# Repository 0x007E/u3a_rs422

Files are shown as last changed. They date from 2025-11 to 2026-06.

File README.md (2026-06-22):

  

# `U3A_rs422` - RS422 - Adapter for U3A



The `U3A_rs422` project is based on a ([THVD1452](#additional-information)) that ist used to change the RX/TX signals to the required differential signal level of TIA/TIA-485-A standard. It can simply be adapted to the [U3A-Module](https://github.com/0x007e/u3a).

> To use it with a [DSUB](https://www.reichelt.de/de/de/shop/produkt/d-sub-stecker_9-pol_flachbandkabel_ohne_isolator-6987) connector it is necessary to create a connector cable that can be plugged into the IDC connector.

| Experience | Level |
|:---|:-----:|
| Soldering | ?% |
| Mechanical  | ?% |

# Downloads

| Type | File | Description |
|:---:|:---:|:---|
| Schematic  | [pdf](https://github.com/0x007E/u3a_rs422/releases/latest/download/schematic.pdf) / [cadlab](https://cadlab.io/project/29767/main/files) | Schematic files |
| Board | [pdf](https://github.com/0x007E/u3a_rs422/releases/latest/download/pcb.pdf) / [cadlab](https://cadlab.io/project/29767/main/files) | Board file |
| Drill | [pdf](https://github.com/0x007E/u3a_rs422/releases/latest/download/drill.pdf) | Drill file |
| BoM | [xlsx](https://github.com/0x007E/u3a_rs422/releases/latest/download/bom.xlsx) / [html](https://github.com/0x007E/u3a_rs422/releases/latest/download/ibom.html) | Bill of Material as Excel/interactive HTML |
| PCB | [zip](https://github.com/0x007E/u3a_rs422/releases/latest/download/kicad.zip) / [tar](https://github.com/0x007E/u3a_rs422/releases/latest/download/kicad.tar.gz) | KiCAD/Gerber/BoM/Drill files |
| Mechanical | [zip](https://github.com/0x007E/u3a_rs422/releases/latest/download/freecad.zip) / [tar](https://github.com/0x007E/u3a_rs422/releases/latest/download/freecad.tar.gz) | FreeCAD/Housing and PCB (STEP/STL) files |

# Hardware

There are two parts of the hardware. The pcb and the housing of the `U3A_rs422`. The pcb is created with [KiCAD](#additional-information) and the housing with [FreeCAD](#additional-information). All files are built with `github actions` so that they are ready for a production environment. The housing is printed with a 3D-printer (`Dremel 3D40`).

## PCB

The circuit board is populated on both sides (Top, Bottom). The best way for soldering the `SMD` components is within a vapor phase soldering system and for the `THT` components with a standard soldering system.

### Top Layer

Top Layer

### Bottom Layer

Bottom Layer

## Mechanical

The housing has a tolerance of `0.2mm` on each side of the case. So the pcb should fit perfectly in the housing. The tolerance can be modified with `FreeCAD` in the `Parameter` Spreadsheet.

### Assembled

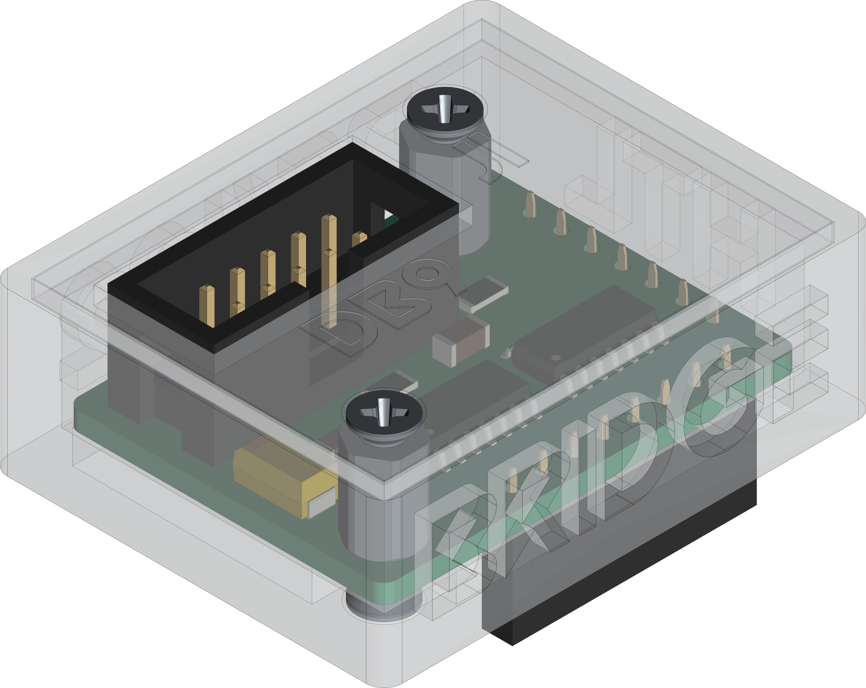
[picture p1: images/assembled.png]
Assembled


### Exploded

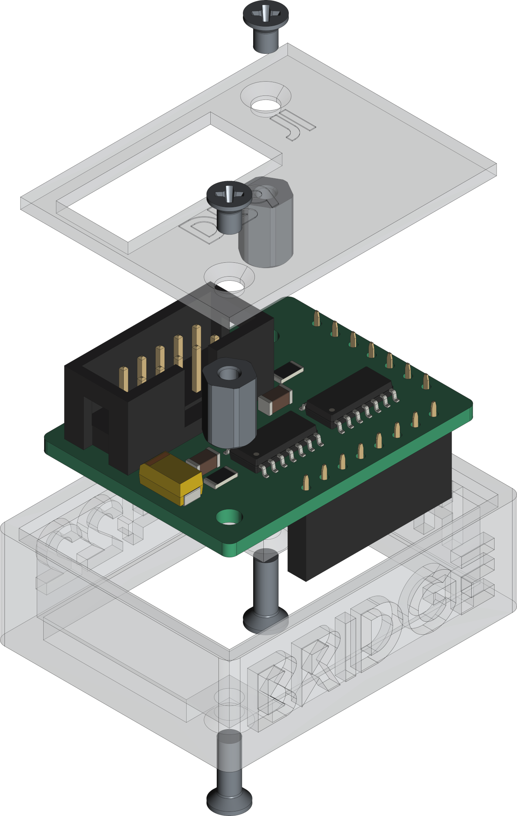
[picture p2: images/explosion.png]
Exploded


# Connection/Setup

The `U3A_rs422` is powerd over the `U3A` board with `5V`. The voltage of the pins are driven by a `THVD1452` for data transmission that meets the TIA/TIA-485-A standard.

## Simple loopback setup for testing purpose

``` bash
#
#            +------------------------------------+           +-----------------------------------+      +---------------------+
#            |J1                      T         J2|           |J2     U                       +---+---+  |                     |
#         +--+--+        U3A_rs422    E        +--+--+     +--+--+    S                U      |  USB  |--+ +-----------------+ |
#     +---+ RTS-| (1) D               R        | VCC +-----+ VCC |    B      UPDI      3      +---+---+  | | TeraTerm        | |
#   L | +-+ RTS+| (2) B               M        | GND +-----+ GND |    /    +---+---+   A          |      | | ~~~~~~~~        | |
#   O +-|-+ CTS-| (3) 9               I        |  X  +-----| PDI |    U    |   |   |              |      | | ~~~~~           | |
#   O   +-+ CTS+| (4)                 N        | CTS +-----+ CTS |    A    |   |   |              |      | | ~~~~~~~~~~~~    | |
#   P     + GND | (5)                 A        | RTS +-----+ RTS |    R    | X | X |              |      | |                 | |
#   B   +-+ RXD+| (6) ~               T        | TXD +-----+ TXD |    T    +---+---+     +-+      |      | +-----------------+ |
#   A +-|-+ RXD-| (7) P   T           I        | RXD +-----+ RXD |    /                 / /       |      |                     |
#   C | +-+ TXD+| (8) W   X           O        +--+--+     +--+--+    U               +-+-+-+-+-+-+      | Computer            |
#   K +---+ TXD-| (9) R   D           N           |           |       P               | 5V  | 3V3 |      |                     |
#         +--+--+     E   E           -> 120Ω     |           |       D               +-----+-----+      +---------------------+
#            |        N   N                       |           |       I         J4                |
#            |  +---+---+---+---+---+---+---+---+ |           | +---+---+---+---+---+---+---+---+ |
#            |  | V | C | C | D | D | D | R | G | |           | | V | C | C | D | D | D | R | G | |
#            +--+ C | B | B | C | T | C | I | N +-+           +-+ C | B | B | C | T | C | I | N +-+
#               | C | 3 | 2 | D | R | R |   | D |               | C | 3 | 2 | D | R | R |   | D |
#               +---+-+-+-+-+---+---+---+---+---+               +---+-+-+-+-+---+---+---+---+---+
#                     |   |                                           |   |
#                     |   +-------------------------------------------|---+
#                     +-----------------------------------------------+
```

# Additional Information

| Type | Link | Description |
|:---:|:---:|:---|
| THVD1452 | [pdf](https://www.ti.com/lit/ds/symlink/thvd1452.pdf) | UART / RS422 level converter |
| KiCAD | [web](https://www.kicad.org/) | KiCAD project page |
| FreeCAD | [web](https://www.freecad.org/) | FreeCAD project page |

---

R. GAECHTER

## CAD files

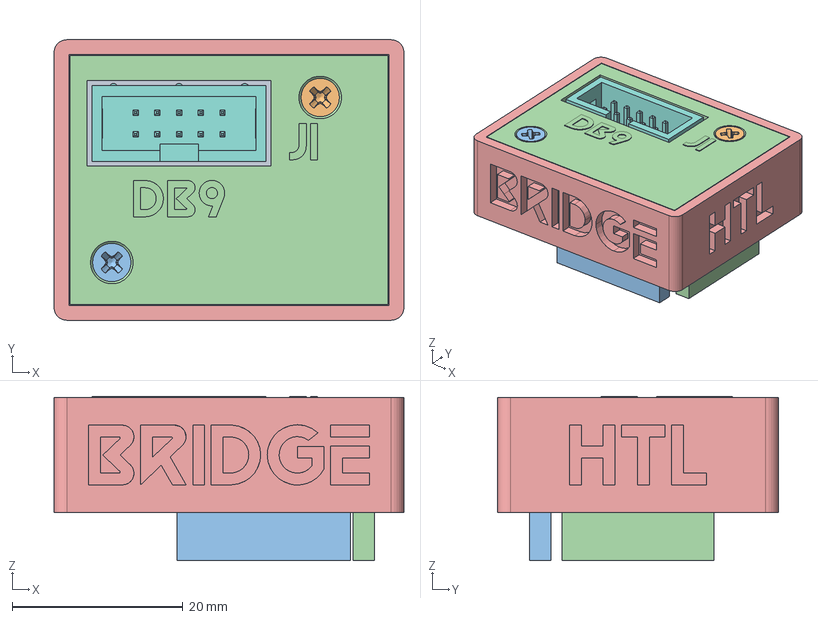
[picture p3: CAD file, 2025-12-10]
mechanical/housing.FCStd
40.9 x 32.8 x 19.2 mm
Pcb_c977
R3_R_1206_3216Metric_602aa173faeb
C3_C_1206_3216Metric_e174f7cd519c
R1_R_1206_3216Metric_1cd0ed1b88fb
C2_C_1206_3216Metric_51f7ab8182d4
U2_SOIC-14_3.9x8.7mm_P1.27mm_957f0b327e66
C1_CP_EIA_6032_28_Kemet_C_aa69b462bfbf
J1_IDC_Header_2x05_P254mm_Vertical_b8abcef818d7
U3_SOIC-14_3.9x8.7mm_P1.27mm_d777186c7664
R2_R_1206_3216Metric_6938828b103d
J4_PinSocket_1x08_P2.54mm_Vertical_36e3868fe61d
J2_PinSocket_1x07_P2.54mm_Vertical_e5fd038025c4
Case
M2.5x7.5x5-Spacer
M2.5x7.5x5-Spacer001
M2.5x8-Screw
M2.5x8-Screw001
M2.5x4-Screw
M2.5x4-Screw001
Acrylglass

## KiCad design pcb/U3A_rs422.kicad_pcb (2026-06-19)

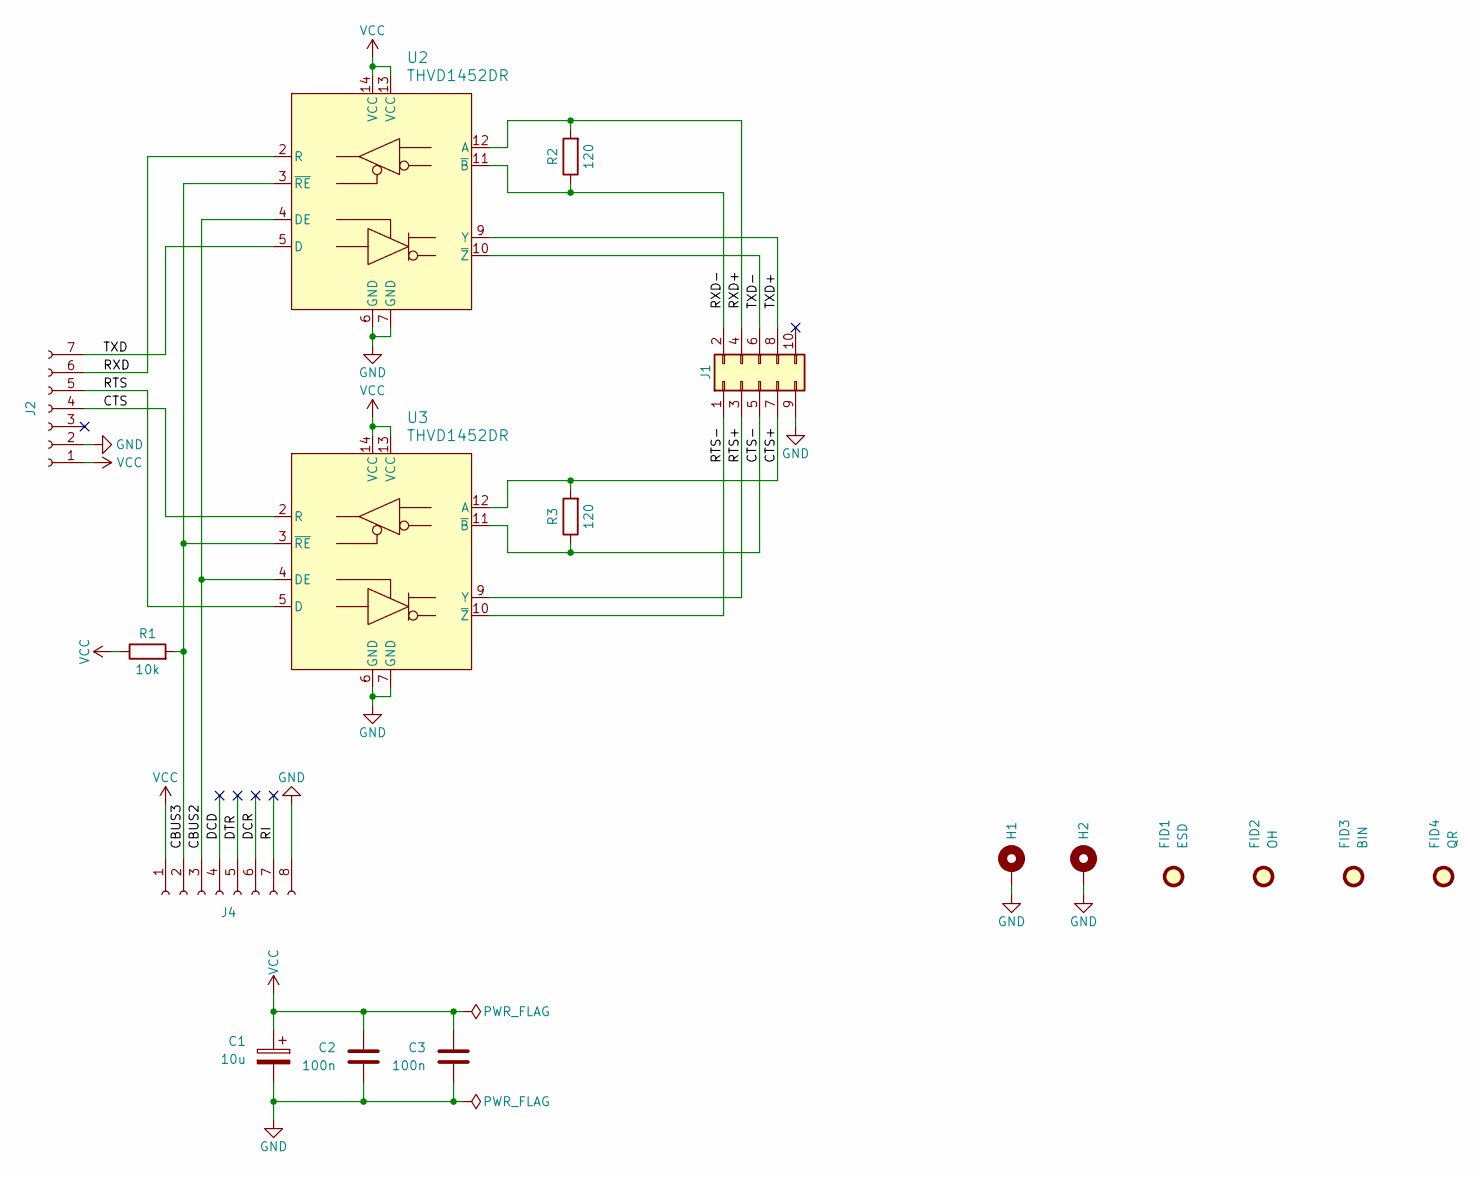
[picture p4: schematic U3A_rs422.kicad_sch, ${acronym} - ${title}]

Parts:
C1: 10u; CP_EIA-6032-28_Kemet-C
C2, C3: 100n; C_1206_3216Metric
FID1: ESD; ESD-Logo_6.6x6mm_SilkScreen
FID2: OH; OSHW-Logo_5.7x6mm_SilkScreen
FID3: BIN; WEEE-Logo_4.2x6mm_SilkScreen
FID4: QR; QR_0x007e_very_small
H1, H2: MountingHole_Pad; MountingHole_2.7mm_M2.5_Pad
J1: Conn_02x05_Odd_Even; IDC-Header_2x05_P2.54mm_Vertical
J2: Conn_01x07_Socket; PinSocket_1x07_P2.54mm_Vertical
J4: Conn_01x08_Socket; PinSocket_1x08_P2.54mm_Vertical
R1: 10k; R_1206_3216Metric
R2, R3: 120; R_1206_3216Metric
U2, U3: THVD1452DR; SOIC-14_3.9x8.7mm_P1.27mm

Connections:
/CBUS2: J4.3, U2.4 (DE), U3.4 (DE)
/CBUS3: J4.2, R1.2, U2.3 (~RE), U3.3 (~RE)
/CTS: J2.4, U3.2 (R)
/CTS+: J1.7, R3.2, U3.12 (A)
/CTS-: J1.5, R3.1, U3.11 (~B)
/DCD: J4.4
/DCR: J4.6
/DTR: J4.5
/RI: J4.7
/RTS: J2.5, U3.5 (D)
/RTS+: J1.3, U3.9 (Y)
/RTS-: J1.1, U3.10 (~Z)
/RXD: J2.6, U2.2 (R)
/RXD+: J1.4, R2.2, U2.12 (A)
/RXD-: J1.2, R2.1, U2.11 (~B)
/TXD: J2.7, U2.5 (D)
/TXD+: J1.8, U2.9 (Y)
/TXD-: J1.6, U2.10 (~Z)
GND: C1.2, C2.1, C3.1, H1.1, H2.1, J1.9, J2.2, J4.8, U2.6 (GND), U2.7 (GND), U3.6 (GND), U3.7 (GND)
VCC: C1.1, C2.2, C3.2, J2.1, J4.1, R1.1, U2.13 (VCC), U2.14 (VCC), U3.13 (VCC), U3.14 (VCC)

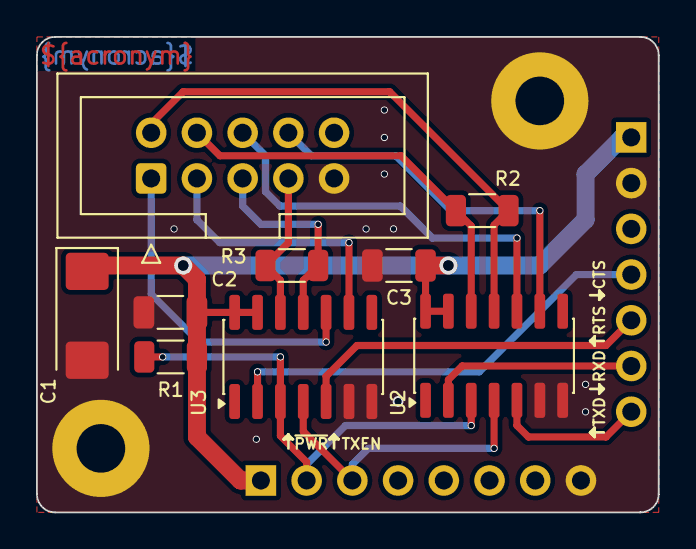
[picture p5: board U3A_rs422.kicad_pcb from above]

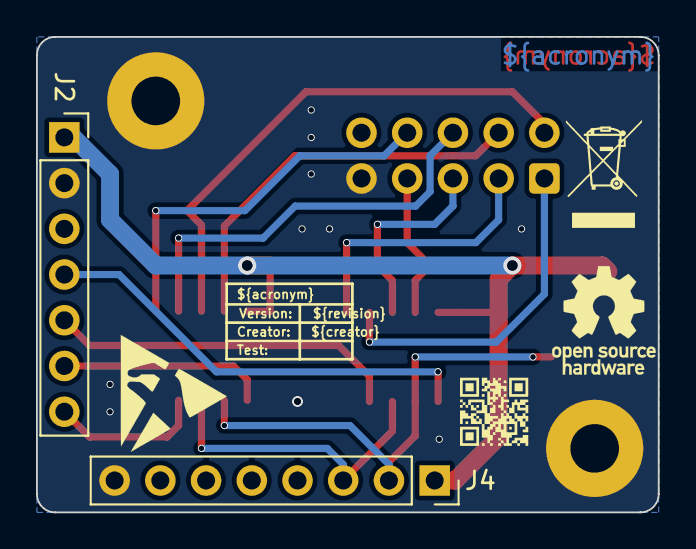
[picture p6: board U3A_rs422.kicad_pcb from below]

Board: 2 copper layers, 34.5 x 26.4 mm, 17 parts (6 on the bottom side), 16 nets.

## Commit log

2025-11-24 Add pcb layout
    [U3A_rs422.kicad_pcb, U3A_rs422.kicad_sch]
2025-11-24 Add mechanical parts
    [housing.FCStd]
2025-11-24 Replacement of pcb
    [housing.FCStd]
2025-11-24 Image update due to circuit board replacement
2025-11-26 Change vendor of parts
    [U3A_rs422.kicad_pcb, U3A_rs422.kicad_sch]
2025-12-10 Rename housing part
    [housing.FCStd]
2026-06-19 Update to KiCAD 9
    [U3A_rs422.kicad_pcb, U3A_rs422.kicad_sch]
2026-06-19 Rename/Add/Remove bom fields
    [U3A_rs422.kicad_pcb, U3A_rs422.kicad_sch]
2026-06-19 Optimize fabrication layer
    [U3A_rs422.kicad_pcb]
2026-06-22 Add missing values in bom

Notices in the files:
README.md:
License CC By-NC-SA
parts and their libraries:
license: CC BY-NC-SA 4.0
